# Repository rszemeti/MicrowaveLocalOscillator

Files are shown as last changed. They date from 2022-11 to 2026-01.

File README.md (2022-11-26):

# MicrowaveLocalOscillator

[][cc-by-sa]

## Description

A simple 2 stage microwave local oscillator using an ADF 4153 to control a Crystek (or similar) VCO

A OCXO reference oscillator is optionally controlled by an ADF4001 when a 10MHz reference signal is present.

## License 

This work is licensed under a
[Creative Commons Attribution-ShareAlike 4.0 International License][cc-by-sa].

[][cc-by-sa]

[cc-by-sa]: http://creativecommons.org/licenses/by-sa/4.0/
[cc-by-sa-image]: https://licensebuttons.net/l/by-sa/4.0/88x31.png
[cc-by-sa-shield]: https://img.shields.io/badge/License-CC%20BY--SA%204.0-lightgrey.svg

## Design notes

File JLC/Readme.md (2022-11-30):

# JLC production data

The files in here will (in theory) produce a well populated board from the JLC PCBA service.

It should look something like this:

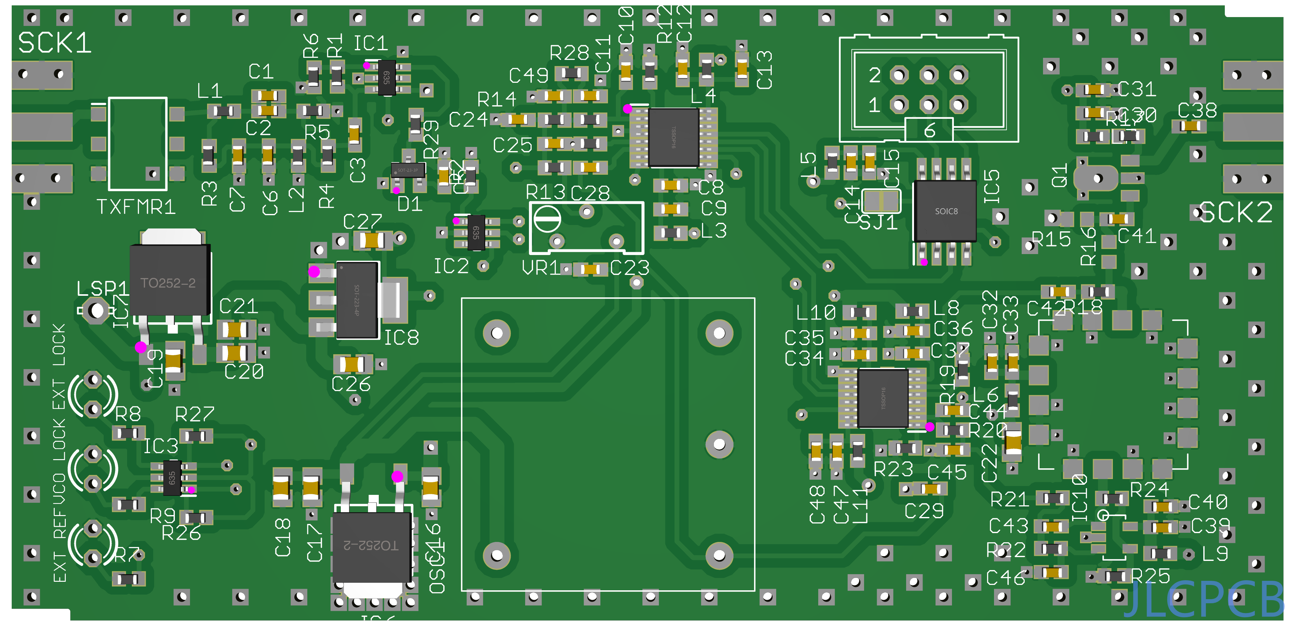
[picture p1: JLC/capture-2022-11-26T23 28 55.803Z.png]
PCB Layout with components


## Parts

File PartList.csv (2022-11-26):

Partlist
Exported from 4001_4153_LO_V2.brd at 26/11/2022 21:42:16
EAGLE Version 6.2.0 Copyright (c) 1988-2012 CadSoft
Assembly variant:
Part     Value                Package                  Library         Position (mm)         Orientation
C1       3.9pF                C0603                    resistor        (22.184 44.983)       R0
C2       27pF                 C0603                    resistor        (22.184 43.713)       R0
C3       100nF                C0603                    resistor        (29.55 41.681)        R90
C5       100nF                C0603                    resistor        (37.17 38.125)        R270
C6       390p                 C0603                    resistor        (22.184 39.903)       R270
C7       2.7nF                C0603                    resistor        (19.644 39.903)       R270
C8       1uF                  C0603                    resistor        (56.474 37.363)       R0
C9       100nF                C0603                    resistor        (56.474 35.331)       R0
C10      22nF                 C0603                    resistor        (52.6538 47.031)      R90
C11      10nF                 C0603                    resistor        (49.616 44.983)       R0
C12      1uF                  C0603                    resistor        (57.49 47.269)        R90
C13      100nF                C0603                    resistor        (62.554 47.269)       R90
C14      1uF                  C0603                    resistor        (71.823 39.3165)      R270
C15      100nF                C0603                    resistor        (73.4105 39.3165)     R270
C16      100nF                C0805                    rcl             (36.07 11.625)        R270
C17      100nF                C0805                    rcl             (25.91 11.625)        R270
C18      10uF                 C0805                    rcl             (23.37 11.625)        R270
C19      100nF                C0805                    rcl             (14.219796875 22.414459375) R270
C20      10uF                 C0805                    rcl             (19.40608125 23.082025) R0
C21      100nF                C0805                    rcl             (19.442696875 25.072253125) R0
C22      100nF                C0805                    rcl             (85.571778125 15.481146875) R270
C23      100nF                C0603                    rcl             (49.6414 30.2002)     R180
C24      100nF                C0603                    rcl             (43.47164375 42.96926875) R180
C25      1uF                  C0603                    rcl             (46.568 40.919)       R0
C26      100nF                C0805                    rcl             (29.389134375 22.11664375) R0
C27      100nF                C0805                    rcl             (31.09234375 32.661259375) R180
C28      1nF                  C0603                    resistor        (49.616 38.887)       R180
C29      1nF                  C0603                    resistor        (78.607853125 11.519221875) R180
C30      100nF                C0603                    resistor        (92.5032375 43.536478125) R0
C31      1uF                  C0603                    resistor        (92.511296875 45.5050375) R0
C32      100nF                C0603                    resistor        (83.816090625 22.27368125) R90
C33      1uF                  C0603                    resistor        (85.58979375 22.28625625) R90
C34      100nF                C0603                    resistor        (72.587615625 22.950003125) R0
C35      1uF                  C0603                    resistor        (72.59211875 24.756921875) R0
C36      1uF                  C0603                    resistor        (77.10156875 24.97775) R180
C37      100nF                C0603                    resistor        (77.104415625 23.03903125) R180
C38      100pF                C0603                    resistor        (100.6980125 42.4133375) R0
C39      100nF                C0603                    resistor        (98.269059375 8.22005625) R0
C40      1uF                  C0603                    resistor        (98.29523125 9.993734375) R0
C41      100pF                C0603                    resistor        (94.5482 34.492921875) R0
C42      100pF                C0603                    resistor        (89.541459375 28.29810625) R180
C43      6.8nF                C0603                    resistor        (88.940515625 8.28975625) R0
C44      22nF                 C0603                    resistor        (80.545046875 18.214171875) R0
C45      10nF                 C0603                    resistor        (80.551871875 14.826984375) R180
C46      15nF                 C0603                    resistor        (88.93343125 4.39005) R0
C47      1uF                  C0603                    resistor        (70.62865625 14.704671875) R270
C48      100nF                C0603                    resistor        (68.841971875 14.70188125) R270
C49      10nF                 C0603                    resistor        (46.5468 44.971)      R180
D1       BAS70-04             SOT23                    diode           (34.122 38.633)       R0
IC1      74LVC2G17GV,125      SOT95P275X110-6N         74LVC2G17GV_125 (32.344 46.507)       R0
IC2      74LVC2G17GV,125      SOT95P275X110-6N         74LVC2G17GV_125 (39.946 33.323)       R0
IC3      74LVC2G17GV,125      SOT95P275X110-6N         74LVC2G17GV_125 (14.074 12.447)       R180
IC4      ADF4001BRUZ          SOP65P640X120-16N        ADF4001BRUZ     (56.728 41.427)       R0
IC5      ATTINY45V-10SU       SOIC127P798X216-8N       ATTINY45V-10SU  (79.79 35.137)        R90
IC6      7805DT               TO252                    linear          (31.136 7.947)        R180
IC7      7809DT               TO252                    linear          (13.994 27.759)       R0
IC8      LD1117AS33TR         SOT223                   v-reg           (29.83038125 27.5757625) R270
IC9      ADF4153BRUZ-RL7      SOP65P640X120-16N        ADF4153BRUZ-RL7 (74.531103125 19.22043125) R180
IC10     MCP6H01              SOT23-5                  RF              (94.32 7.3275)        R0
L1       8.2uH                R0603                    resistor        (18.374 43.713)       R180
L2       82nH                 R0603                    resistor        (24.724 39.903)       R90
L3       100nH                R0603                    resistor        (56.474 33.299)       R0
L4       100nH                R0603                    resistor        (59.522 47.269)       R270
L5       100nH                R0603                    resistor        (70.2355 39.3165)     R270
L6       100nH                R0603                    resistor        (85.601953125 19.025) R270
L7       100nH                R0603                    resistor        (92.484778125 41.541925) R180
L8       100nH                R0603                    resistor        (77.094775 26.646446875) R180
L9       100nH                R0603                    resistor        (98.232809375 5.972478125) R0
L10      100nH                R0603                    resistor        (72.5892375 26.526909375) R0
L11      100nH                R0603                    resistor        (72.418071875 14.728709375) R90
LED1     EXT AVAIL            LED3MM                   led             (7.184 6.827)         R90
LED2     EXT LOCK             LED3MM                   led             (7.184 19.527)        R90
LED3     OP VCO LOCK          LED3MM                   led             (7.184 13.177)        R90
LSP1     LSP13                LSP13                    solpad          (7.42 26.695)         R0
OSC1     CTI_OSC              CTI_OSC                  RF              (51.14 15.265)        R90
OSC2     CRSYTELEK_127        CRYSTEK_VCO              RF              (87.880125 13.1765375) R0
Q1       PGA105+              SOT89                    zetex           (93.685 37.998)       R90
R1       1K                   R0603                    rcl             (28.04 46.663)        R90
R2       100K                 R0603                    rcl             (39.456 38.125)       R90
R3       51R                  R0603                    rcl             (17.104 39.903)       R270
R4       51R                  R0603                    rcl             (27.264 39.903)       R90
R5       51R                  R0603                    rcl             (25.994 43.713)       R180
R6       3K3                  R0603                    rcl             (26.06 46.605)        R270
R7       51R                  R0603                    rcl             (10.248 3.811)        R180
R8       51R                  R0603                    rcl             (10.248 16.257)       R180
R9       51R                  R0603                    rcl             (10.248 10.161)       R180
R10      51R                  R0603                    rcl             (49.616 40.919)       R0
R11      150R                 R0603                    rcl             (49.616 42.951)       R180
R12      5K1                  R0603                    rcl             (54.696 47.015)       R90
R13      47K                  R0603                    rcl             (46.568 38.887)       R180
R14      10K                  R0603                    rcl             (46.568 42.951)       R180
R15      TO TASTE             R0603                    rcl             (91.144071875 34.4852375) R0
R16      TO TASTE             R0603                    rcl             (93.862121875 31.707459375) R90
R17      10R                  R0603                    rcl             (95.5166 41.5712)     R180
R18      18K                  R0603                    rcl             (92.919965625 28.291325) R180
R19      51R                  R0603                    rcl             (81.33871875 21.648103125) R270
R20      150R                 R0603                    rcl             (80.542315625 16.506390625) R0
R21      27k                  R0603                    rcl             (89.062628125 10.718628125) R0
R22      39k                  R0603                    rcl             (88.911121875 6.401003125) R0
R23      5K1                  R0603                    rcl             (76.494209375 14.970465625) R180
R24      18K                  R0603                    rcl             (94.11759375 10.66824375) R180
R25      10K                  R0603                    rcl             (94.316440625 4.063278125) R180
R26      10K                  R0603                    rcl             (16.004 9.034)        R180
R27      10K                  R0603                    rcl             (16 16)               R180
R28      150R                 R0603                    rcl             (48.02 46.923)        R180
R29      100K                 R0603                    rcl             (34.752 42.559)       R270
SCK1     SMA-142-0701-871/876 J502-ND-142-0701-871/876 con-coax        (0.254 42.363)        R0
SCK2     SMA-142-0701-871/876 J502-ND-142-0701-871/876 con-coax        (108.798 42.363)      R180
SJ1                           SJ                       jumper          (74.448 36.041)       R180
SV1                           ML6                      con-harting-ml  (78.52 45.551)        R0
TXFMR1   ADT1-1WT-1+          SOP254P691X284-6N        ADT1-1WT-1+     (11.008 40.919)       R0
VR1      1K0                  RTRIM64Y                 resistor        (49.3054 32.6186)     R270

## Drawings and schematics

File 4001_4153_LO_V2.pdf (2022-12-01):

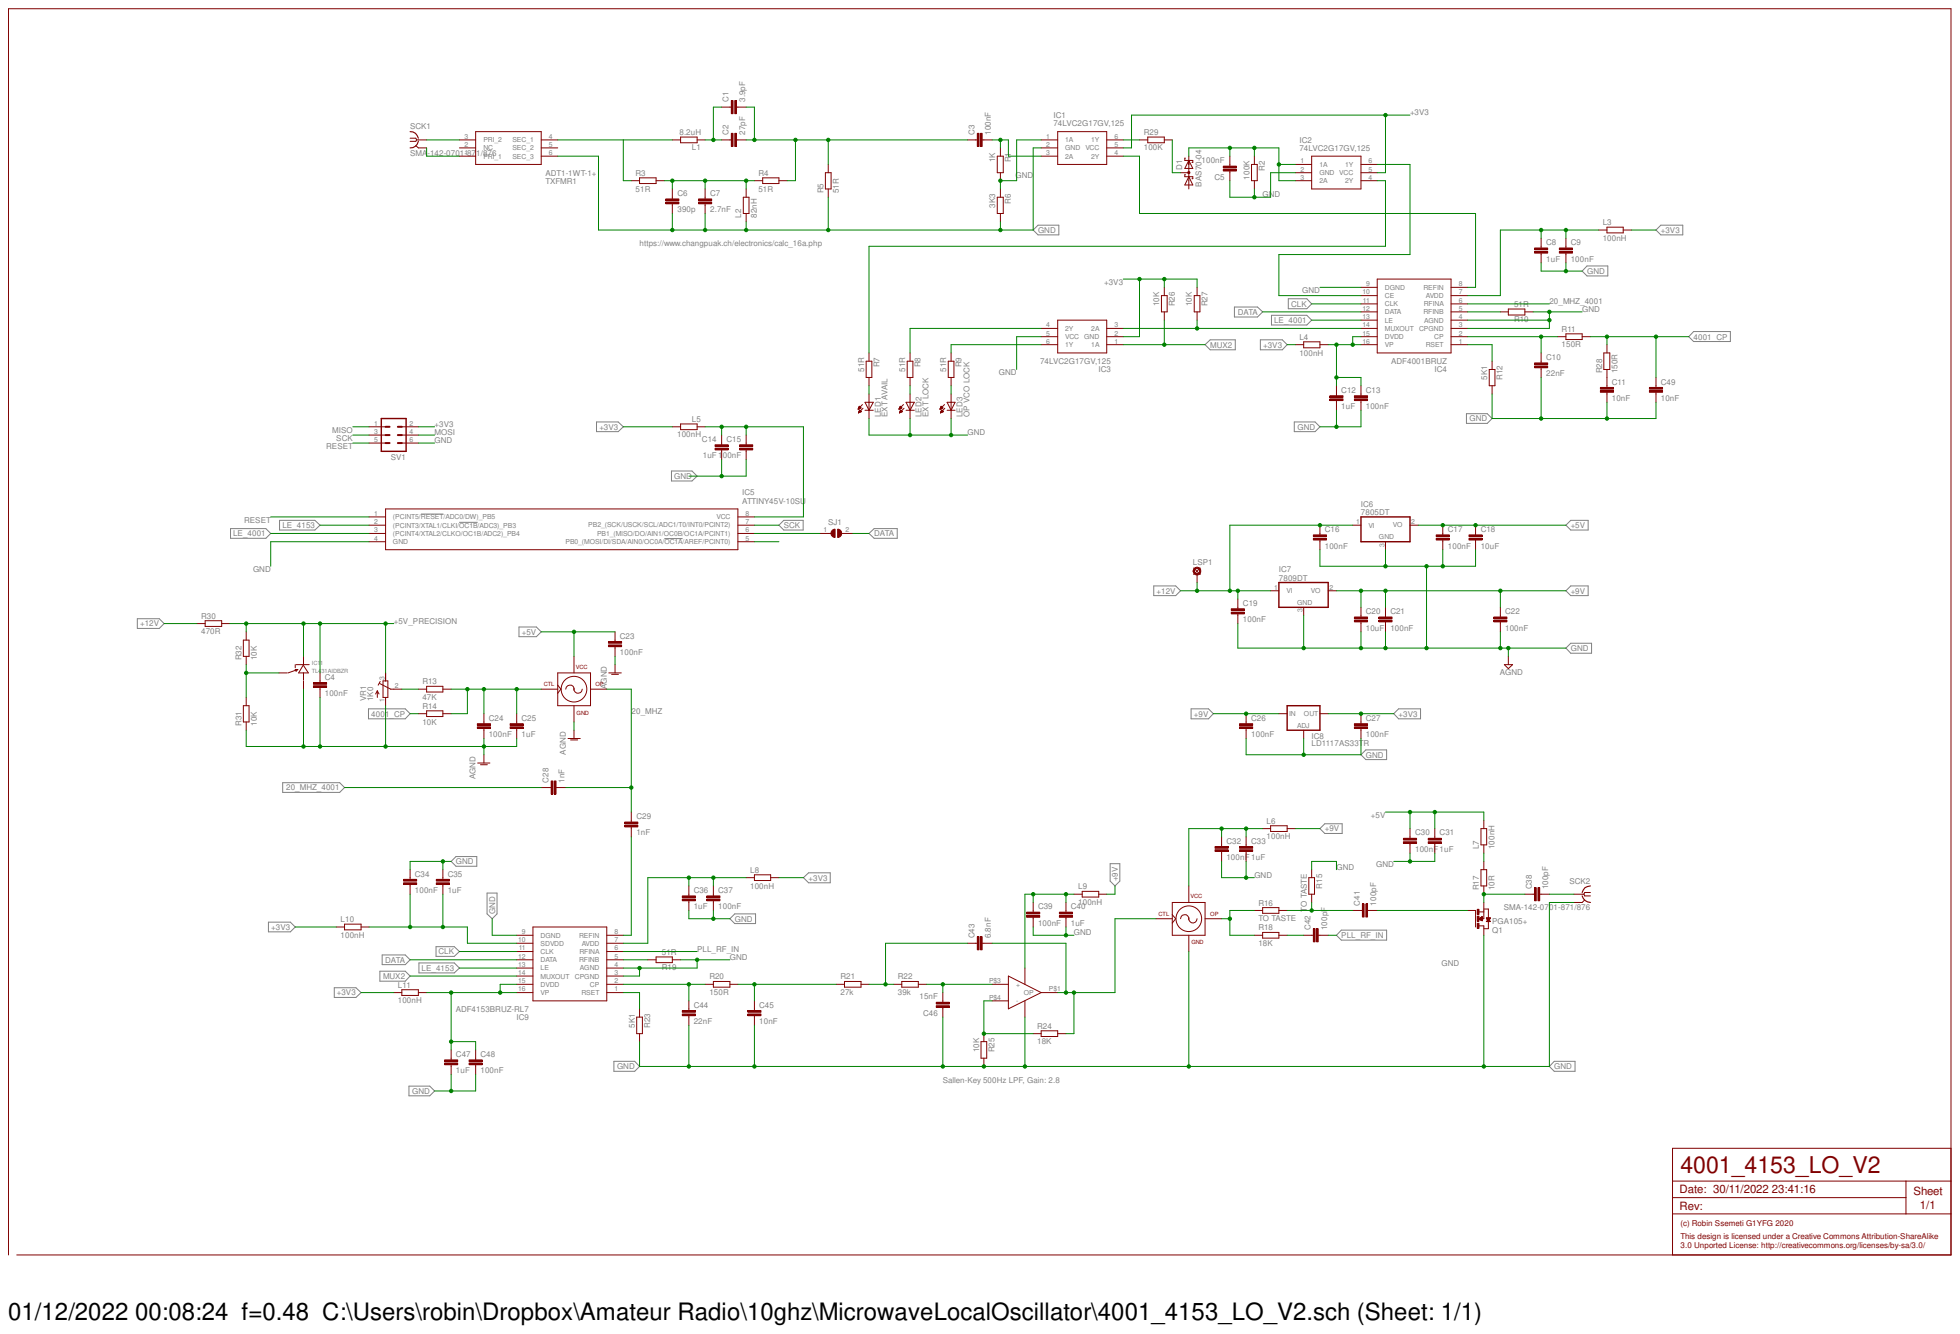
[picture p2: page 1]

https://www.changpuak.ch/electronics/calc_16a.php

Sallen-Key 500Hz LPF, Gain: 2.8

(c) Robin Ssemeti G1YFG 2020
This design is licensed under a Creative Commons Attribution-ShareAlike
3.0 Unported License: http://creativecommons.org/licenses/by-sa/3.0/

01/12/2022 00:08:24 f=0.48 C:\Users\robin\Dropbox\Amateur Radio\10ghz\MicrowaveLocalOscillator\4001_4153_LO_V2.sch (Sheet: 1/1)

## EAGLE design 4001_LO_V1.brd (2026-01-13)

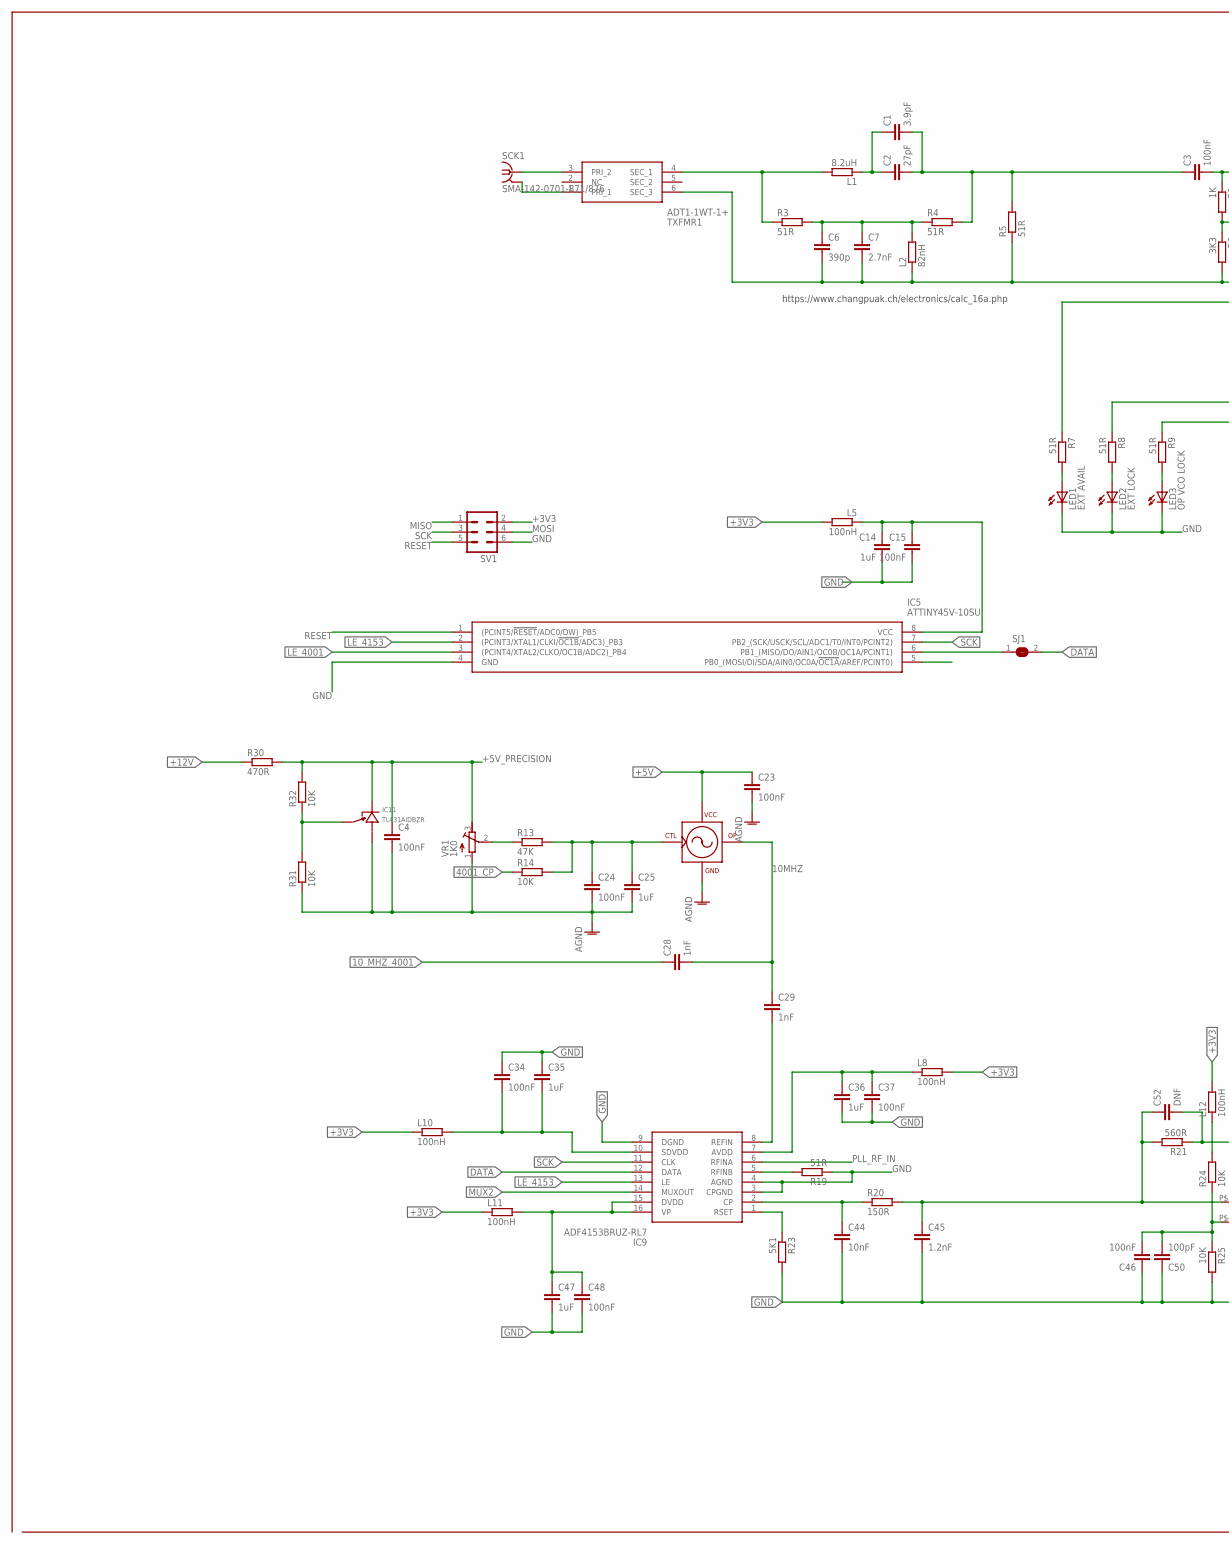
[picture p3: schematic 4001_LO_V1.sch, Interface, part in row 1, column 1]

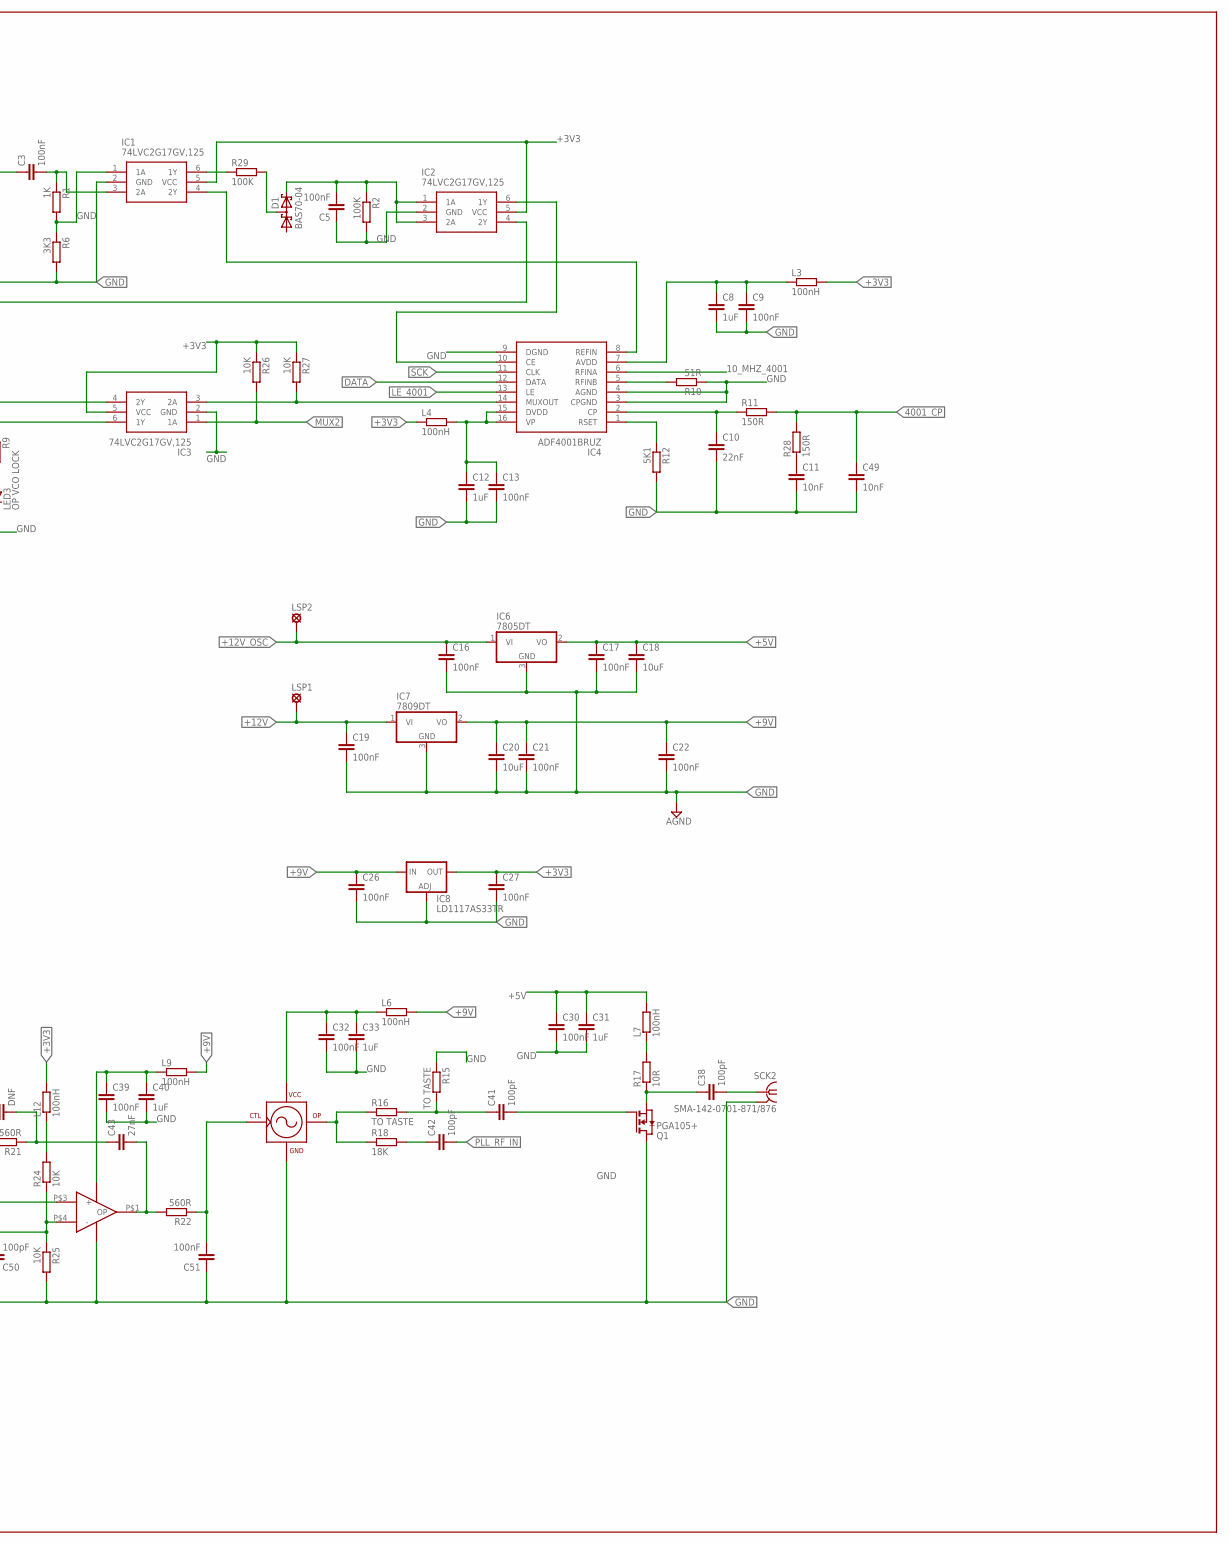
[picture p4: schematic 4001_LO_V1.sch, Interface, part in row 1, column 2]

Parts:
C1: 3.9pF; C0603
C2: 27pF; C0603
C3, C4, C5, C9, C13, C15, C23, C24, C30, C32, C34, C37, C39, C46, C48, C51: 100nF; C0603
C6: 390p; C0603
C7: 2.7nF; C0603
C8, C12, C14, C25, C31, C33, C35, C36, C40, C47: 1uF; C0603
C10: 22nF; C0603
C11, C44, C49: 10nF; C0603
C16, C17, C19, C21, C22, C26, C27: 100nF; C0805
C18, C20: 10uF; C0805
C28, C29: 1nF; C0603
C38, C41, C42, C50: 100pF; C0603
C43: 27nF; C0603
C45: 1.2nF; C0603
C52: DNF; C0603
D1: BAS70-04; SOT23
IC1: 74LVC2G17GV,125; SOT95P275X110-6N
IC2, IC3: 74LVC2G17GV,125; SOT95P275X110-6N; MANUFACTURER_PART_NUMBER 74LVC2G17GV,125; MOUSER_PART_NUMBER 771-74LVC2G17GV-G
IC4: ADF4001BRUZ; SOP65P640X120-16N; JLC C207717
IC5: ATTINY45V-10SU; SOIC127P798X216-8N
IC6: 7805DT; TO252
IC7: 7809DT; TO252
IC8: LD1117AS33TR; SOT223; JLC C108495
IC9: ADF4153BRUZ-RL7; SOP65P640X120-16N
IC10: MCP6H01T-E/LT; SOT23-5; MPN MCP6H01T-E/LT
IC11: TL431AIDBZR; SOT23L
L1: 8.2uH; R0603
L2: 82nH; R0603
L3, L4, L5, L6, L7, L8, L9, L10, L11, L12: 100nH; R0603
LED1: EXT AVAIL; LED3MM
LED2: EXT LOCK; LED3MM
LED3: OP VCO LOCK; LED3MM
LSP1, LSP2: LSP13
OSC1: CTI_OSC
OSC2: CRSYTELEK_127; CRYSTEK_VCO
Q1: PGA105+; SOT89
R1: 1K; R0603
R2, R29: 100K; R0603
R3, R4, R5, R7, R8, R9, R10, R19: 51R; R0603
R6: 3K3; R0603
R11, R20, R28: 150R; R0603
R12, R23: 5K1; R0603
R13: 47K; R0603
R14, R24, R25, R26, R27, R31, R32: 10K; R0603
R15, R16: TO TASTE; R0603
R17: 10R; R0603
R18: 18K; R0603
R21, R22: 560R; R0603
R30: 470R; R0603
SCK1: SMA-142-0701-871/876; J502-ND-142-0701-871/876
SCK2: SMA-142-0701-871/876; J502-ND-142-0701-871/876; MPN 142-0701-871
SJ1: SJ
SV1: ML6; MPN MC-254-06-00-ST-DIP
TXFMR1: ADT1-1WT-1+; SOP254P691X284-6N
VR1: 1K0; RTRIM64Y; MPN 3296Y-1-103LF

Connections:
10MHZ: C28.2, C29.1, OSC1.OUT (OP)
10MHZ_REF: C29.2, IC9.8 (REFIN)
10_MHZ_4001: C28.1, IC4.6 (RFINA)
4001_CP: C49.1, R11.2, R14.1, R28.2
+3V3: C27.1, IC1.5 (VCC), IC2.5 (VCC), IC3.5 (VCC), IC8.4 (OUT), L3.2, L4.1, L5.2, L8.2, L10.1, L11.1, L12.2, R26.1, R27.1, SV1.2
+5V: C17.1, C18.1, C23.1, C30.1, C31.1, IC6.2 (VO), L7.2, OSC1.VCC
+5V_PRECISION: C4.1, IC11.G (CATHODE), R30.2, R32.2, VR1.3 (A)
+8V: C32.1, C33.1, L6.1, OSC2.P$14 (VCC)
+9V: C20.1, C21.1, C22.1, C26.1, IC7.2 (VO), IC8.3 (IN), L6.2, L9.2
+12V: C19.1, IC7.1 (VI), LSP1.MP, R30.1
+12V_OSC: C16.1, IC6.1 (VI), LSP2.MP
AVDD: C36.1, C37.1, IC9.7 (AVDD), L8.1
DATA: IC4.12 (DATA), IC9.12 (DATA), SJ1.2
DVDD: C47.1, C48.1, IC9.15 (DVDD), IC9.16 (VP), L11.2
DVDD1: C12.1, C13.1, IC4.15 (DVDD), IC4.16 (VP), L4.2
FILT_EXT_REF: C1.2, C2.2, C3.1, R4.2, R5.2
GND: C4.2, C5.1, C6.2, C7.2, C8.2, C9.2, C10.2, C11.2, C12.2, C13.2, C14.2, C15.2, C16.2, C17.2, C18.2, C19.2, C20.2, C21.2, C22.2, C23.2, C24.2, C25.2, C26.2, C27.2, C30.2, C31.2, C32.2, C33.2, C34.1, C35.1, C36.2, C37.2, C39.2, C40.2, C44.2, C45.2, C46.1, C47.2, C48.2, C49.2, C50.1, C51.1, IC1.2 (GND), IC2.2 (GND), IC3.2 (GND), IC4.3 (CPGND), IC4.4 (AGND), IC4.9 (DGND), IC5.4 (GND), IC6.3 (GND), IC7.3 (GND), IC8.1 (ADJ), IC9.3 (CPGND), IC9.4 (AGND), IC9.9 (DGND), IC10.P$2 (-VE), IC11.D (ANODE), L2.1, LED1.K (C), LED2.K (C), LED3.K (C), OSC1.GND, OSC2.P$1 (GND), OSC2.P$3 (GND), OSC2.P$4 (GND), OSC2.P$5 (GND), OSC2.P$6 (GND), OSC2.P$7 (GND), OSC2.P$8 (GND), OSC2.P$9 (GND), OSC2.P$11 (GND), OSC2.P$12 (GND), OSC2.P$13 (GND), OSC2.P$15 (GND), OSC2.P$16 (GND), Q1.2 (D), R2.2, R5.1, R6.2, R10.1, R12.2, R15.1, R19.1, R23.2, R25.2, R31.1, SCK1.G@1 (GND), SCK1.G@2 (GND), SCK1.G@3 (GND), SCK1.G@4 (GND), SCK2.G@1 (GND), SCK2.G@2 (GND), SCK2.G@3 (GND), SCK2.G@4 (GND), SV1.6, TXFMR1.1 (PRI_1), TXFMR1.6 (SEC_3), VR1.1 (E)
LE_4001: IC4.13 (LE), IC5.3 ((PCINT4/XTAL2/CLKO/OC1B/ADC2)_PB4)
LE_4153: IC5.2 ((PCINT3/XTAL1/CLKI/!OC1B!/ADC3)_PB3), IC9.13 (LE)
LOOP_IN: C45.1, C52.1, IC10.P$3 (+), R20.2, R21.2
MISO: IC5.6 (PB1_(MISO/DO/AIN1/OC0B/OC1A/PCINT1)), SJ1.1, SV1.1
MOSI: IC5.5 (PB0_(MOSI/DI/SDA/AIN0/OC0A/!OC1A!/AREF/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), SV1.4
MUX2: IC3.1 (1A), IC9.14 (MUXOUT), R26.2
unnamed: IC9.5 (RFINB), R19.2
unnamed: IC9.1 (RSET), R23.1
unnamed: C39.1, C40.1, IC10.P$6 (+VE), L9.1
unnamed: OSC2.P$10 (OP), R16.1, R18.1
unnamed: C46.2, C50.2, IC10.P$4 (-), R24.1, R25.1
unnamed: IC4.5 (RFINB), R10.2
unnamed: C43.1, C52.2, R21.1
unnamed: C43.2, IC10.P$1 (OP), R22.2
unnamed: C42.1, R18.2
unnamed: C41.2, Q1.1 (G)
unnamed: C38.1, Q1.3 (S), R17.1
unnamed: C41.1, R15.2, R16.2
unnamed: IC4.1 (RSET), R12.1
unnamed: C10.1, IC4.2 (CP), R11.1
unnamed: C44.1, IC9.2 (CP), R20.1
unnamed: C3.2, IC1.3 (2A), R1.1
unnamed: LED3.A, R9.2
unnamed: R13.1, VR1.2 (S)
unnamed: IC3.4 (2Y), R8.1
unnamed: L7.1, R17.2
unnamed: C11.1, R28.1
unnamed: D1.3 (C1A2), R29.2
unnamed: C5.2, D1.2 (C2), IC2.1 (1A), IC2.3 (2A), R2.1
unnamed: LED2.A, R8.2
unnamed: IC3.3 (2A), IC4.14 (MUXOUT), R27.2
unnamed: IC3.6 (1Y), R9.1
unnamed: LED1.A, R7.2
unnamed: IC2.4 (2Y), R7.1
unnamed: IC1.6 (1Y), R29.1
unnamed: C1.1, C2.1, L1.1
unnamed: C24.1, C25.1, OSC1.REF (CTRL), R13.2, R14.2
unnamed: L1.2, R3.1, TXFMR1.4 (SEC_1)
unnamed: SCK1.1, TXFMR1.3 (PRI_2)
unnamed: C6.1, C7.1, L2.2, R3.2, R4.1
unnamed: C8.1, C9.1, IC4.7 (AVDD), L3.1
unnamed: IC1.1 (1A), R1.2, R6.1
unnamed: IC1.4 (2Y), IC4.8 (REFIN)
unnamed: L12.1, R24.2
unnamed: C51.2, OSC2.P$2 (CTRL), R22.1
unnamed: IC11.S (CTRL), R31.2, R32.1
OUTPUT: C38.2, SCK2.1
PLL_RF_IN: C42.2, IC9.6 (RFINA)
RESET: IC5.1 ((PCINT5/!RESET!/ADC0/DW)_PB5), SV1.5
SCK: IC4.11 (CLK), IC5.7 (PB2_(SCK/USCK/SCL/ADC1/T0/INT0/PCINT2)), IC9.11 (CLK), SV1.3
SDVDD: C34.2, C35.2, IC9.10 (SDVDD), L10.2
SDVDD1: IC2.6 (1Y), IC4.10 (CE)
VCC_UP: C14.1, C15.1, IC5.8 (VCC), L5.1

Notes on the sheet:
https://www.changpuak.ch/electronics/calc_16a.php

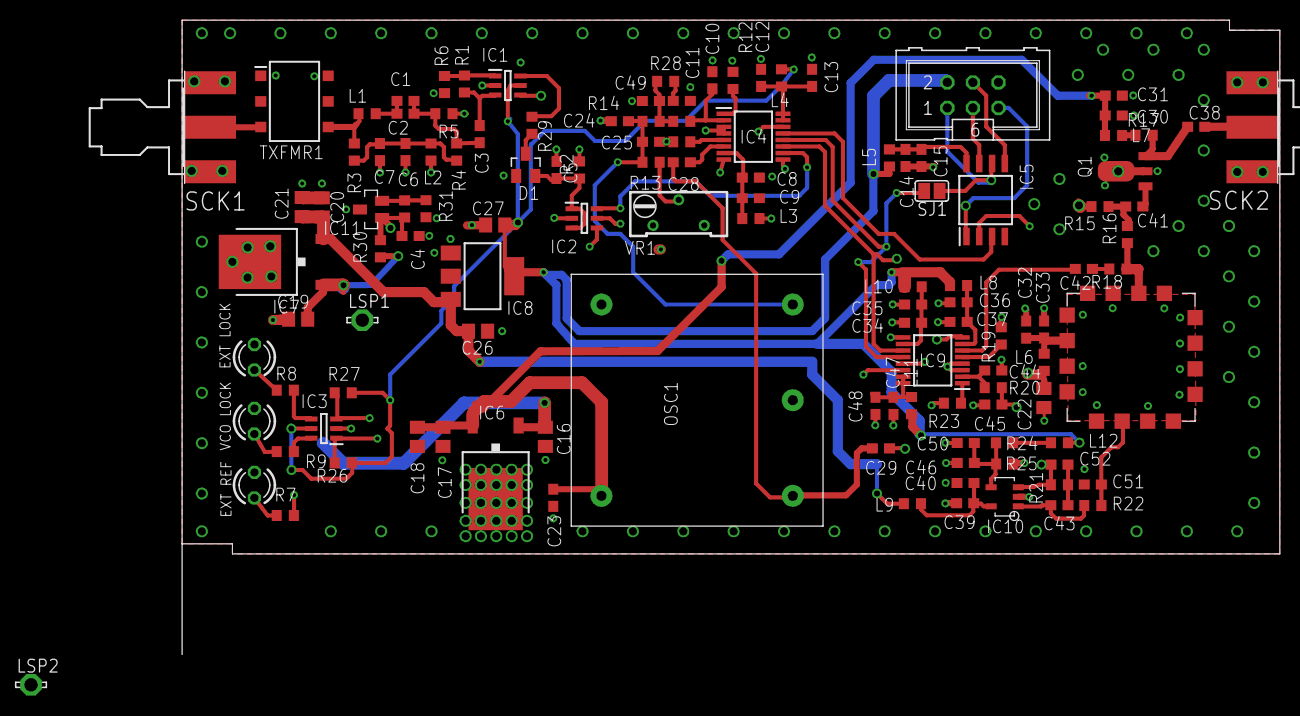
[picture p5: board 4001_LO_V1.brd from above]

Board: 4 copper layers, 109.0 x 53.0 mm, 122 parts (0 on the bottom side), 70 nets.

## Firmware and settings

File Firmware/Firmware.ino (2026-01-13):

// From PA0MHE's code.

#include <tinySPI.h>
#include <avr/sleep.h>

#define ADF4001 DDB4      // 4001                
#define ADF4153 DDB3      // 4153        


uint32_t Reg4001[5] =  {
  0x1FC092, 
  0x100004, 
  0x000101,
} ; // 10Mhz oscillator, ref 10MHz, Muxout: digital lock detect

uint32_t Reg4153[6] =  {
  0x000003, /* clear spurs mode R3*/
  0x3C7,    /* write desired spurs mode R3*/
  0x1386,   /* Enable counter reset R2 =R2+4 */
  0x104015,  /* Write R1 */
  0x3E0008, /* Write R0 */
  0x1382    /* Disable counter reset  R2*/
 } ; 

void setup() {
  SPI.begin();

  pinMode(ADF4001, OUTPUT);
  digitalWrite(ADF4001, LOW);

  pinMode(ADF4153, OUTPUT);
  digitalWrite(ADF4153, LOW);

  delay(500);
  ADFSet(Reg4001, 3, ADF4001);
  delay(500);
  ADFSet(Reg4153, 6, ADF4153);
  delay(500);


}


// Go to sleep, if for some reason you wake up again, go back to sleep.
void loop() {
  set_sleep_mode(SLEEP_MODE_PWR_DOWN);
  sleep_enable();
  sleep_mode();
}

void ADFSet(uint32_t reg[], int c, byte LE) {
  for (int i = 0; i < c; i++) {
    ADFWriteRegister32(reg[i], LE);
  }
}

void ADFWriteRegister32(const uint32_t value, byte LE) //Program data into one of the 32bits register, the register that is selected by the four LSBs.
{
  digitalWrite(LE, LOW);
  for (int i = 3; i >= 0; i--)               // loop through 4 x 8bits
    SPI.transfer((value >> 8 * i) & 0xFF);   // shift , mask and send octet via SPI
  digitalWrite(LE, HIGH);                    // Load Enable rising edge the data stored in the shift register
  delay(1);
  digitalWrite(LE, LOW);                     //
}

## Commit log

2022-11-25 Add files via upload
    Initial Commit
    [4001_4153_LO_V2.brd, 4001_4153_LO_V2.sch]
2022-11-25 Size change and pre-release tweaks
    Updated sizes, sorted out component name positions on PCB, added 10R to PGA105+drive ref Andy JNT
    [4001_4153_LO_V2.brd, 4001_4153_LO_V2.sch]
2022-11-25 Gerbers for test boards
    Layer stack sorted out, gerbers produced in JLC format
    [4001_4153_LO_V2.GBL, 4001_4153_LO_V2.GBO, 4001_4153_LO_V2.GBP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]
2022-11-26 Misc circuit revisions
    Updated loop filter on 4001, added pullups to MUXOUT
    [4001_4153_LO_V2.brd, 4001_4153_LO_V2.sch]
2022-11-26 Minor mods
    Added text to rear silk,
    moved a few components around the 4001 loop filter
    [4001_4153_LO_V2.brd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]
2022-11-26 Soldering mods
    Moved components to clear board edges on underside for soldering to box.
    [4001_4153_LO_V2.brd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]
2022-11-26 Thermal mods
    Rotated 5V reg, ref GM4ISM
    [4001_4153_LO_V2.brd]
2022-11-26 Tracking
    Rotated 5v reg
    tracking around output device
    [4001_4153_LO_V2.brd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]
2022-11-26 Output and detector
    Moved resistor in output stage to power feed
    Swapped C for R in 10MHz detector
    [4001_4153_LO_V2.brd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]
2022-11-26 multi-turn
    replaced single turn pot with multiturn
    [4001_4153_LO_V2.brd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]
2022-11-26 Tracking corrections
    Minor clearance issues
    [4001_4153_LO_V2.GBL, 4001_4153_LO_V2.GBS, 4001_4153_LO_V2.GKO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]
2022-11-26 JLC Release
    [4001_4153_LO_V2.brd, 4001_4153_LO_V2.sch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]
2022-11-26 JLC Production files added
    The files in the "JLC" folder can be uploaded to the JLC PCBA service to get a pretty complete PCB ...
    [4001_4153_LO_V2.GBL, 4001_4153_LO_V2.GBP, 4001_4153_LO_V2.GBS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]
2022-11-30 JLC release
    As issued to JLC
    [4001_4153_LO_V2.brd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]
2022-12-01 Update 4001_4153_LO_V2.pdf
    JLC release schematic
2023-09-09 filter loop update
    [4001_4153_LO_V2.brd, 4001_4153_LO_V2.sch]
2023-09-11 Ref synth updates
    Firmware working for ADF4001
    Various board updates, ref input still needs works
    [4001_4153_LO_V2.brd, 4001_4153_LO_V2.sch]

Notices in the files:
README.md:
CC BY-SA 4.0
